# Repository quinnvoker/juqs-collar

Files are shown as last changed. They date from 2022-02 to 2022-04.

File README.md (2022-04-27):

# JUQS Collars for Sanjuks V6

A personal project to develop additional collar types and "gate" shapes for Sanjuks V6 levers. I devoted most of my time towards fine-tuning the "OCTN" model (nobi pro-like shape), but there are several other shapes available.

I'm pretty happy with the results, but don't wish to pursue production myself, so I've made this repo open source. 

Some pre-rendered OCTN collars are included in the `renders` folder. You can render collars with different shapes and profiles using the source files and OpenScad.

I have no plans to develop this further and will not provide support. I've done a little bit of explaining in comments, but for the most part you'll just have to hop into OpenScad and mess around with `juqs_collar.scad` if you want to play around with it. Good luck! This was my first-ever OpenScad project so be prepared to find a mess if you go digging.

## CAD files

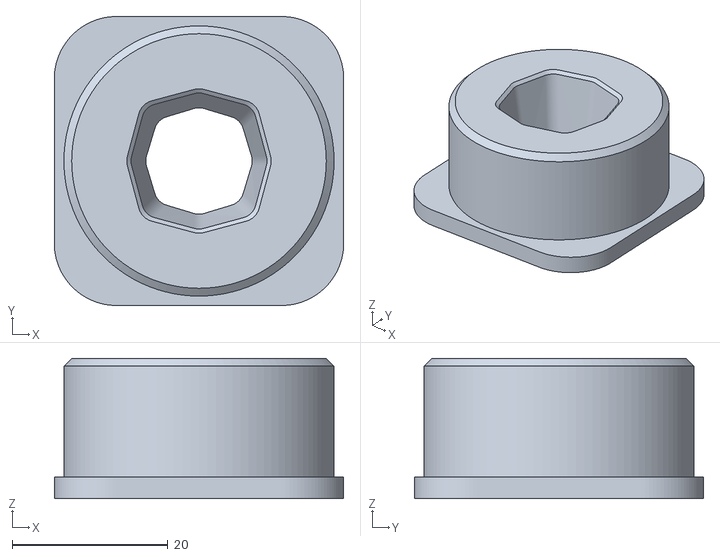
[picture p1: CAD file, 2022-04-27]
renders/PROD/JUQS-V3.1-OCTN-SN-FULL.stl
37.2 x 37.1 x 18.0

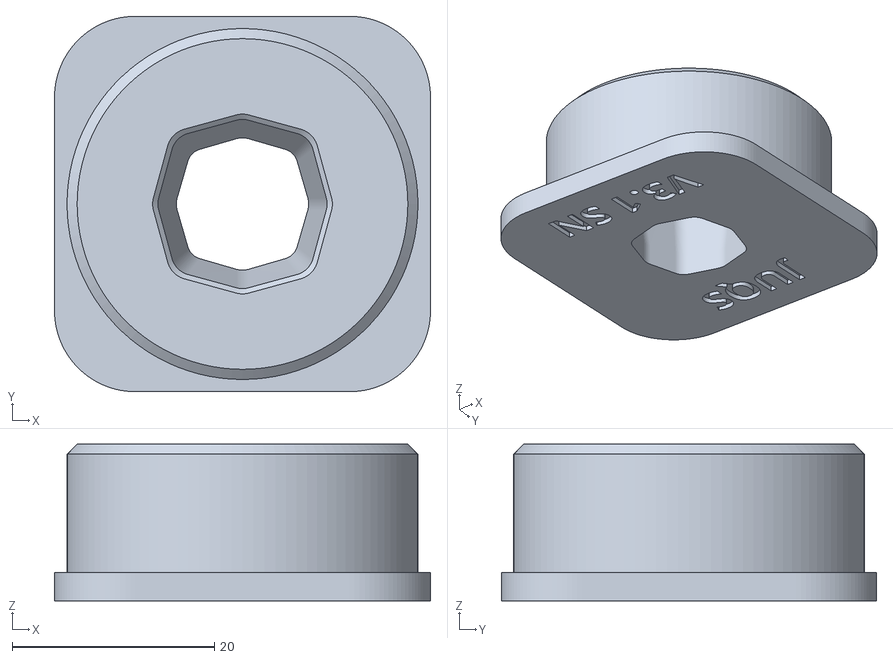
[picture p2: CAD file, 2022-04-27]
renders/JUQS-V3.1-OCTN-SN-ISLAND.stl
37.2 x 37.1 x 15.5

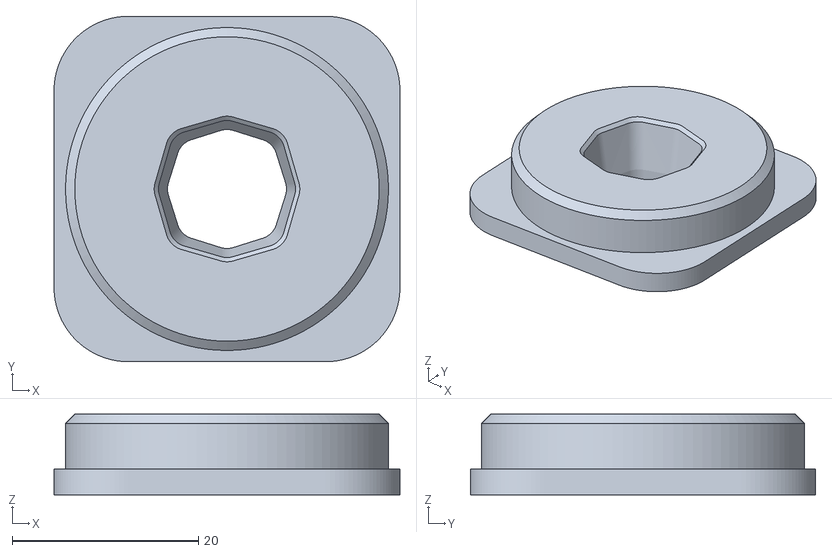
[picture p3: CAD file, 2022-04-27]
renders/PROD/JUQS-V3.1-OCTN-SN-SHORT.stl
37.2 x 37.1 x 8.70

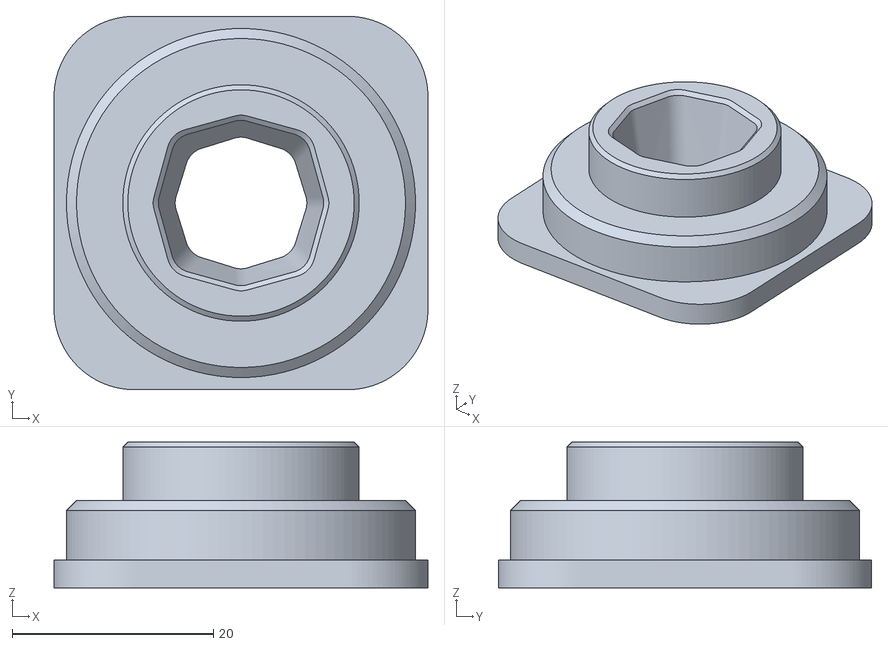
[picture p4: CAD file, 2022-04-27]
renders/PROD/JUQS-V3.1-OCTN-SN-STEPPED.stl
37.2 x 37.1 x 14.5

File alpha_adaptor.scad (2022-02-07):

use<juqs_collar.scad>;
$fn = 100;

/*
measurements

total_z = 7.6

upper_x = 59.6
upper_y = 59.6
upper_z = 4
upper_r = 2 // ? maybe

lower_x = 52.6
lower_y = 52.6
lower_z = 3.6
lower_r = 13 // ? maybe

screw_hole_d = 4.8
screw_hole_bevel_d = 8.2
screw_hole_bevel_h = 1.8
screw_hole_padding_lower = 1.8
*/

alpha_adaptor();

module alpha_adaptor() {
  union(){
    lower();
    translate([0, 0, 3.6])
      upper();
  }
}

module upper(solo = false, h = 4, size = 59.6, r = 3.5){
  difference() {
    rounded_rect(h = h, size = size, r = r);
    screw_holes();
    center_hole();
    translate([0,0,h - 2.8])
      base(b = 0);
    if(solo)
      guide_posts();
  }
}

module lower(solo = false, h = 3.6, size = 52.6, r = 15){
  difference() {
    union(){
      rounded_rect(h = h, size = size, r = r);
      if(solo)
        guide_posts();
    }
    screw_holes(r2 = 4.8/2);
    center_hole();
  }
}

module center_hole() {
  cylinder(h = 10, r = 35 / 2);
}

module guide_posts(h = 7.6, r = 6.5 / 2) {
  rotate([0,0,45])
    screw_holes(h = 7.6, r1 = r, r2 = r, pos = 61.8 / 2);
}

module screw_holes(h = 10, r1 = 4.8 / 2, r2 = 5.6 / 2, pos = 52.6 / 2 - 1.8){
  offset = pos - r1;
  chamfer_height = r2 - r1;
  translate([offset, 0, 0]){
    cylinder(h = h, r = r1);
    translate([0, 0 ,4 - chamfer_height])
      cylinder(h = chamfer_height, r1 = r1, r2 = r2);
  }
  translate([-offset, 0, 0]){
    cylinder(h = h, r = r1);
    translate([0, 0 ,4 - chamfer_height])
      cylinder(h = chamfer_height, r1 = r1, r2 = r2);
  }
  translate([0, offset, 0]){
    cylinder(h = h, r = r1);
    translate([0, 0 ,4 - chamfer_height])
      cylinder(h = chamfer_height, r1 = r1, r2 = r2);
  }
  translate([0, -offset, 0]){
    cylinder(h = h, r = r1);
    translate([0, 0 ,4 - chamfer_height])
      cylinder(h = chamfer_height, r1 = r1, r2 = r2);
  }
}

module rounded_rect(h, size, r) {
 corner_offset = size / 2 - r;
 hull(){
  translate([corner_offset, corner_offset, 0])
    cylinder(h = h, r = r);
  translate([corner_offset, -corner_offset, 0])
    cylinder(h = h, r = r);
  translate([-corner_offset, corner_offset, 0])
    cylinder(h = h, r = r);
  translate([-corner_offset, -corner_offset, 0])
    cylinder(h = h, r = r);
 }
}

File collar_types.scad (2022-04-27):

SHORT = [8.7, [1.6, 0.5], false];
FULL = [18, [4.6, 0.5], false];
STEPPED = [8.7, [2.6, 0.5], true];
FLAT = [2.1 + 2.8, [0.5, 0.5], false];
ISLAND = [8.7 + 5.8 + 1, [2.6, 0.5], false];

CIR = "CIR";
SQR = "SQR";
OCT = "OCT";
OCTR = "OCTR";
OCTN = "OCTN";
SQRN = "SQRN";

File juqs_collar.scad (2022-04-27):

include<round_gates.scad>;
include<shape_gate.scad>;
include<shapes.scad>;
include<collar_types.scad>;

$fn = 100;

VERSION = "V3.1";
collar_r = 34.7/2;
grommet_dist = 6.8; //distance the grommet sits below this component
grommet_depth = 6.4; //thickness of grommet (when compressed)
pivot_depth = grommet_dist + grommet_depth / 2;

/*
  Update the following line to change which kind of collar is being rendered.
  Available model values: 
    CIR (circle) 
    SQR (square)
    OCT (octagon),
    OCTR (octagon with round notches, seimitsu octo-like)
    OCTN (octagon with deep corners, nobi pro-like)
    SQRN (square with cardinal notches, nobi standard-like)
  Available collar values:
    SHORT (standard short or "chopped" collar)
    FULL (standard full collar)
    STEPPED (stepped collar, like Bandit F3)
    FLAT (flat collar, like alphas)
    ISLAND (unique, almost-full collar. only beveled part of top protrudes when using AFS case)
  For different throw types, change number in brackets (throw_types[x]):
    0 ("S": Emulates full throw of standard sanjuks v6 circle gate)
    1 ("SQ": Reduces throw for SQR model, corners will have same throw as "S" but cardinals are short)
    2 ("SN": Similar to "SQ", but slightly larger. Tuned for OCTN model)
*/
juqs(model = OCTN, collar = FULL, throw_type= throw_types[2], production = false);

/* 
  change shaft_r to match radius of shaft you wish to use. for example, a 10mm shaft:
  shaft_r = (10/2)/cos(180/$fn);

  NOTE: adjusts fit and dimensions of collar to retain same throw as standard 9mm shaft.
  if you want to increase/decrease throw, modify or add values in throw_types
*/
shaft_r = (9/2)/cos(180/$fn);

/*
  throw types are arrays with two values:
    - the max desired cardinal throw angle in degrees (diagonal throw is dependent on gate shape)
    - a string to use as an identifier, embossed on bottom of collar if not production mode
*/
throw_types = [
  [10, "S"],
  [10 / sqrt(2), "SQ"],
  [10 / sqrt(2 / 1.4), "SN"]
];

module juqs(model = CIR, ver = VERSION, collar = SHORT, throw_type = throw_types[0], shaft_r = shaft_r, pivot_depth = pivot_depth, production = false) {
  throw = throw_type[0];
  collar_h = collar[0];
  bevel = collar[1];
  stepped = collar[2];
  step_h = stepped ? 5.8 : 0;
  rotate([0,0,0]) {
    difference() {
      difference() {
        union() {
          base(b=0);
          collar(collar_h);
          if(stepped)
            collar(h = collar_h + step_h, r = 23.5 / 2, bevel =0.5);
        };
        inner_bevel(collar_h + step_h, bevel[1]) {
          hollow(model, throw, shaft_r, pivot_depth, collar_h + step_h, bevel);
       };
      };
      if(!production) {
        font = "Open Sans:style=Bold";
        fontsize = 4.2;
        translate([0,0,-0.1]) {
          mirror([1,0,0]) {
            linear_extrude(0.7){
              translate([0, 10.6, 0])
                text(str("JUQS"), font=font, size=fontsize, halign = "center");
              translate([0, -14.75, 0])
                text(str(ver, " ", throw_type[1]),font=font, size=fontsize, halign = "center");
            }
          };
        }
      }
    };
  };
};

module hollow(model = CIR, throw, shaft_r, pivot_depth, collar_h, bevel){
  translate([0,0,-pivot_depth]){
    if(model == CIR)
      cir_gate(throw, shaft_r);
    if(model == SQR)
      shape_gate(sqr_poly, throw, shaft_r, 0, collar_h, pivot_depth, bevel);
    if(model == OCT)
      shape_gate(oct_poly, throw, shaft_r, 0.5, collar_h, pivot_depth, bevel);
    if(model == OCTR)
      octr_gate(throw, shaft_r);
    if(model == OCTN)
      shape_gate(octn_poly, throw, shaft_r, 0.5, collar_h, pivot_depth, bevel);
    if(model == SQRN)
      qrn_gate(throw, shaft_r);
  }
}

module inner_bevel(collar_height, t_size = 0.8){
  if(t_size > 0) {
    translate([0,0,collar_height - t_size])
      linear_extrude(height = t_size + 0.1, scale = 1 + 0.125 * (t_size + 0.1))
        projection(cut = true)
          translate([0,0,-(collar_height - t_size)])
            children();
  }
  children();
}

module shaft(r, depth, rotation) {
  translate([0,0,-depth]){
    rotate(rotation)
      cylinder(h = 100, r = shaft_r);
  }
};

module base (size = [37.18, 37.12, 2.8], r = 8, b=0.30) {
  w = size.x;
  l = size.y;
  h = size.z;
  corner_offset = [w/2 - r, l/2 - r];
  hull() {
    translate([corner_offset.x, corner_offset.y, 0]){
      cylinder(b, r - b, r);
      translate([0,0,b])
        cylinder(h=h - b * 2, r=r);
      translate([0,0,h - b])
        cylinder(b, r, r - b);
    }
    translate([-corner_offset.x, corner_offset.y, 0]){
      cylinder(b, r - b, r);
      translate([0,0,b])
        cylinder(h=h - b * 2, r=r);
      translate([0,0,h - b])
        cylinder(b, r, r - b);
    }
    translate([corner_offset.x, -corner_offset.y, 0]){
      cylinder(b, r - b, r);
      translate([0,0,b])
        cylinder(h=h - b * 2, r=r);
      translate([0,0,h - b])
        cylinder(b, r, r - b);
    }
    translate([-corner_offset.x, -corner_offset.y, 0]){
      cylinder(b, r - b, r);
      translate([0,0,b])
        cylinder(h=h - b * 2, r=r);
      translate([0,0,h - b])
        cylinder(b, r, r - b);
    }
  };
};

// use h=18 for full collar
module collar (h = 8.7, r = (34.7/2), bevel = 1) {
  union() {
    cylinder(h=h - bevel, r=r);
    translate([0,0,h - bevel]) {
      cylinder(h=bevel, r1 = r, r2= r - bevel);
    }
  }
}

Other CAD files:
math.scad
round_gates.scad
round_poly.scad
round_polygon.scad
shape_gate.scad
shapes.scad

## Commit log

2021-12-29 Import prototype collar file
    [JUQS-collar.scad]
2021-12-29 Make base function self-contained
    [JUQS-collar.scad]
2021-12-29 Make collar function self-contained
    [JUQS-collar.scad]
2021-12-29 Add circular pivot shape
    [JUQS-collar.scad]
2021-12-29 Remove all internal bevels
    [JUQS-collar.scad]
2021-12-30 Simplify arguments for most modules
    [JUQS-collar.scad]
2021-12-30 Improve round nobi
    [JUQS-collar.scad]
2021-12-30 Improve nroct and use max_throw_circle
    [JUQS-collar.scad]
2021-12-30 Major cleanup and refactor
    [JUQS-OCTNR-V1A.stl, JUQS-collar.scad]
2022-01-06 Add bevel to circle hollow
    [JUQS-collar.scad]
2022-01-06 Add bevel to square collar
    [JUQS-collar.scad]
2022-01-06 Add bevel to octagon collar
    [JUQS-collar.scad]
2022-01-06 Add bevel to round octagon collar
    [JUQS-collar.scad]
2022-01-06 Add bevel to nobi round oct collar
    [JUQS-collar.scad]
2022-01-06 WIP of polygon-based OCTN
    [JUQS-collar.scad]
2022-01-06 Better OCTN WIP
    [JUQS-collar.scad]
2022-01-07 More OCTN work, last before total refactor
    [JUQS-collar.scad]
2022-01-08 Add round gates library
    [round_gates.scad]
2022-01-08 Make use of round gates
    [JUQS-collar.scad, round_gates.scad]
2022-01-08 Start setting up helpers for poly gates
    [poly_gates.scad]
2022-01-08 Add polyhedron generation from throw and shape
    [poly_gates.scad]
2022-01-08 Add octn poly
    [poly_gates.scad]
2022-01-08 Add shape gate definition, with sharpness
    [poly_gates.scad]
2022-01-09 Invert sharpness wip
    [poly_gates.scad]
2022-01-09 Invert sharpness now scales [-1:0]
    [poly_gates.scad]
2022-01-09 Scrap inverse sharpness
    [poly_gates.scad]
2022-01-09 Switch focus to 2d to avoid 3d mink
    [poly_gates.scad, round_polygon.scad]
2022-01-09 Add non-zero scaling
    [round_polygon.scad]
2022-01-09 Round poly now perfectly fits radius
    [round_polygon.scad]
2022-01-09 Add size to round poly
    [round_polygon.scad]
2022-01-09 Add math library
    [math.scad, round_polygon.scad]
2022-01-09 Use round poly in poly gates
    [math.scad, poly_gates.scad, round_poly.scad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]
2022-01-10 Complete simple shape gate
    [poly_gates.scad, shape_gate.scad]
2022-01-10 Update collar to use new gates
    [JUQS-collar.scad, juqs_collar.scad, shapes.scad]
2022-01-10 Add bottom bevel
    [juqs_collar.scad]
2022-01-10 Add top bevel
    [juqs_collar.scad]
2022-01-10 Adjust gate for undersized hole
    [juqs_collar.scad]
2022-01-12 Update bevels and OCTN corner size
    [JUQS-OCTN-V1B.stl, JUQS-OCTNR-V1B.stl, juqs_collar.scad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]
2022-01-12 Improve corners of OCTNR
    [juqs_collar.scad, round_gates.scad]
2022-01-12 Restore asymmetrical bevels
    [juqs_collar.scad]
2022-01-13 Lower pivot point for better slappage
    [JUQS-OCTN-V1C.stl, JUQS-OCTN-V1D.stl, juqs_collar.scad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]
2022-01-14 More pivot point adjust, version E
    [JUQS-OCTN-V1E.stl, juqs_collar.scad]
2022-01-14 Perfect SJ throw and better collar def., ver G
    [juqs_collar.scad]
2022-01-15 Allow for defining different throw types
    [JUQS-CIR-9.616-V2.0.stl, JUQS-OCTN-V1F.stl, JUQS-OCTN-V1G.stl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]
2022-01-19 Fix SQRN corners, add step collar and S+SN throws
    [JUQS-CIR-10-V2.0.stl, JUQS-CIR-9.75-V2.0.stl, JUQS-OCTN-S-V2.2-STEPPED.stl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]
2022-01-19 Raised pivot point to prevent hitting collar top
    [JUQS-OCTN-SN-V2.2.1-STEPPED.stl, juqs_collar.scad]
2022-01-25 Fix pivot, throw, and add flush collar option
    [2.4-GROUP-PRINT.3mf, JUQS-OCTN-SN-V2.4-FLUSH.stl, JUQS-OCTN-SN-V2.4-FULL.stl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]
2022-01-29 Remove base bevel due to printing issues
    [2.4-GROUP-PRINT.3mf, JUQS-V2.6-CIR-B-FULL.stl, JUQS-V2.6-GROUP-PRINT-JESTURE.3mf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]
2022-02-03 Improve text, add alpha adaptor
    [JUQS-V2.8-OCTN-SN-ISLAND.stl, alpha_adaptor.scad, alpha_adaptor.stl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]
2022-02-05 Add 2-piece adapter and alpha collar
    [alpha_adaptor.scad, alpha_adaptor_0.2.stl, alpha_adaptor_lower.stl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]
2022-02-05 Improved throw accuracy of alpha collar
    [JUQS-V2.9-OCTN-AN-FLAT.stl, JUQS-V2.9-OCTN-AN-STEPPED.stl, juqs_alpha_collar.scad]
2022-02-07 Improve individual part rendering
    [JUQS-ALPHA-CONVERTER.3mf, JUQS-ALPHA-CONVERTER.step, JUQS-ALPHA-CONVERTER.stl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]
2022-02-07 Upgraded shape gate for 3.0
    [shape_gate.scad]
2022-04-27 Repo cleanup
    [JUQS-ALPHA-CONVERTER.3mf, JUQS-ALPHA-CONVERTER.step, JUQS-ALPHA-CONVERTER.stl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]
2022-04-27 Final version for now (3.1)
    [JUQS-V3.1-OCTN-SN-FULL.stl, JUQS-V3.1-OCTN-SN-ISLAND.stl, JUQS-V3.1-OCTN-SN-SHORT.stl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]
2022-04-27 Cleanup for release
    [collar_types.scad, juqs_alpha_collar.scad, juqs_collar.scad]
2022-04-27 Improve descriptions
    [juqs_collar.scad]
